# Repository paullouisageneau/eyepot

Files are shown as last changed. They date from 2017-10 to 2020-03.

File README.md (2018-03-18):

# Eyepot
A four-legged teapot robot with a camera

Read my blog articles for more information:

https://chapelierfou.org/blog/eyepot-a-creepy-teapot.html

https://chapelierfou.org/blog/eyepot-programming.html

https://vimeo.com/260540824

Eyepot

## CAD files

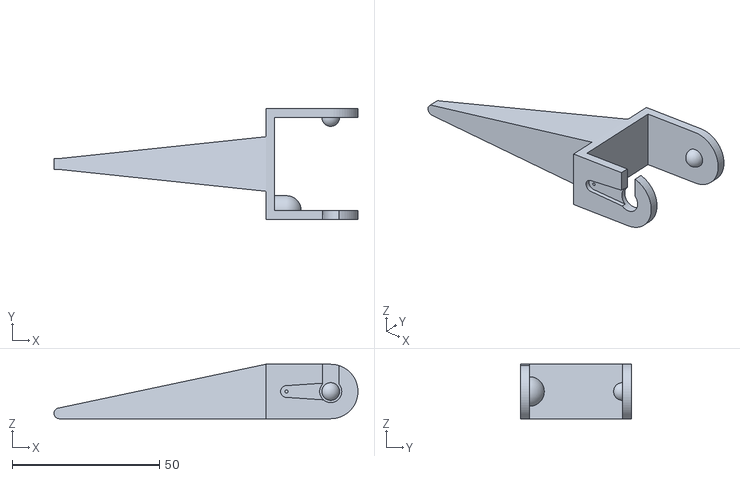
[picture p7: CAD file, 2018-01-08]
models/leg2.stl
103.1 x 37.5 x 18.5

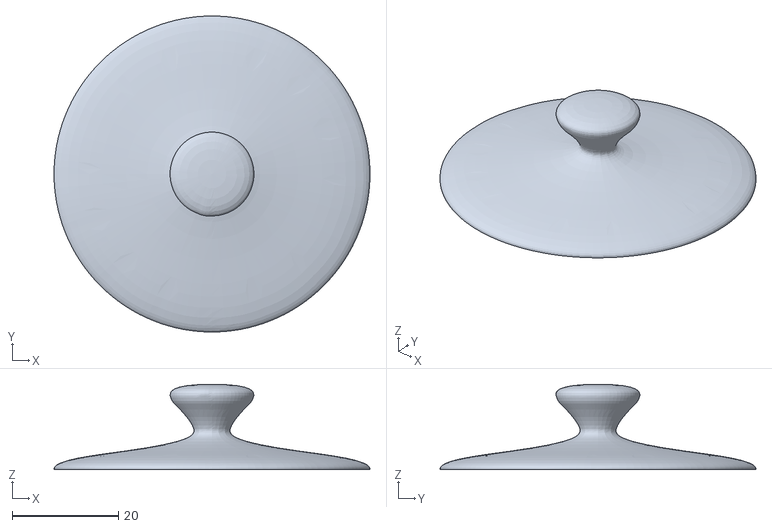
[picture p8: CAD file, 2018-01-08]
models/utah_lid.stl
59.4 x 59.4 x 16.0

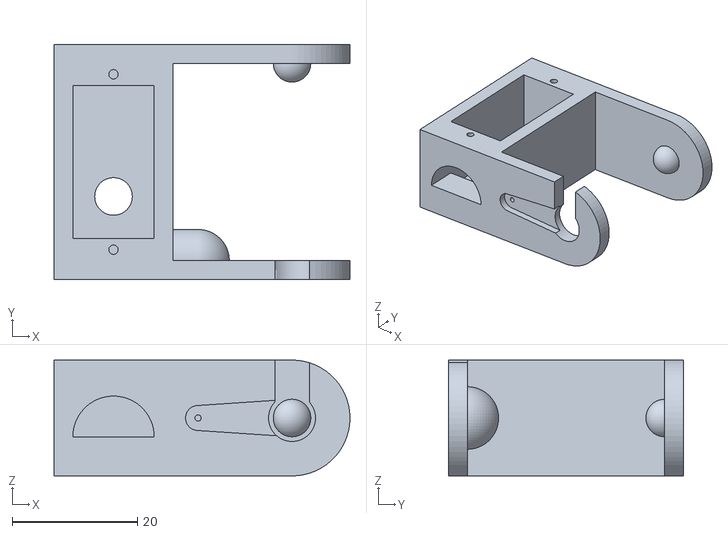
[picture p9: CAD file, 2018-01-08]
models/hip2.stl
47.2 x 37.5 x 18.5

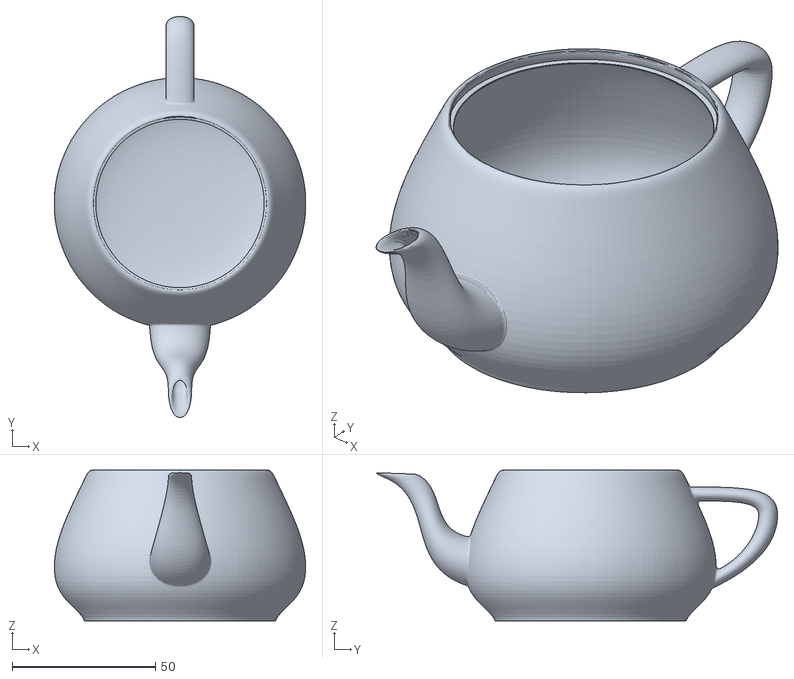
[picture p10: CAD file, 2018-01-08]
models/utah_teapot.stl
87.7 x 140.0 x 52.6

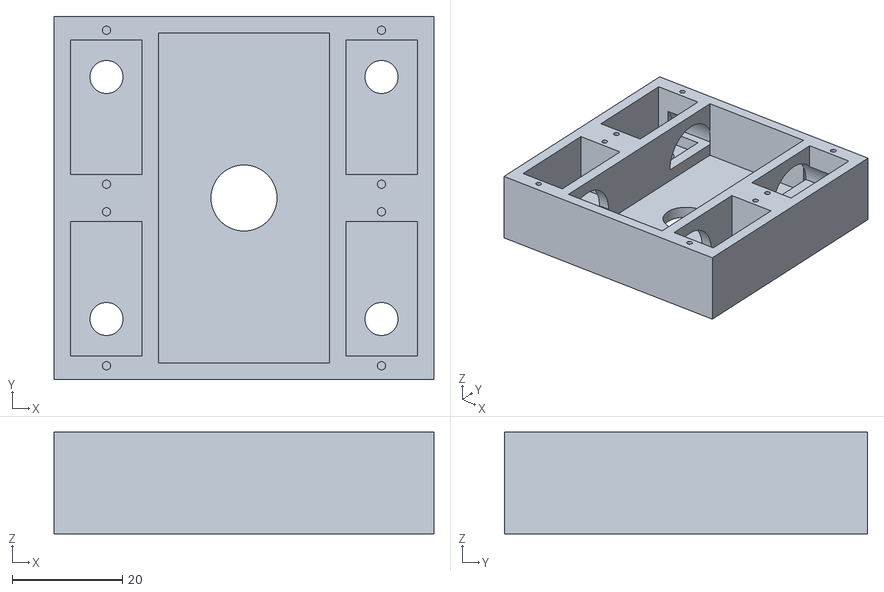
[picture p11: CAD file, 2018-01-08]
models/platform.stl
69.0 x 66.0 x 18.5

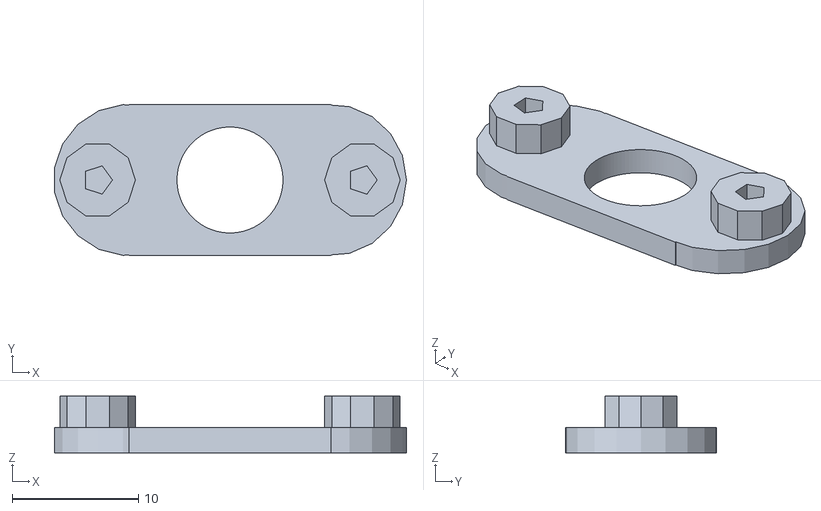
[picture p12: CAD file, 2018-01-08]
models/camera.stl
27.9 x 12.0 x 4.50

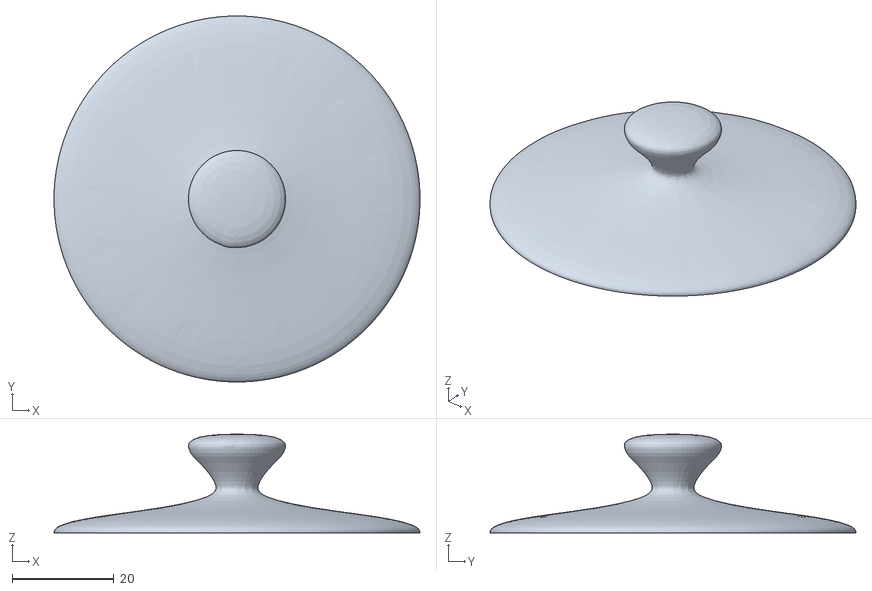
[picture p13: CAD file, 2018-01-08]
models/lid.stl
71.8 x 71.8 x 19.4

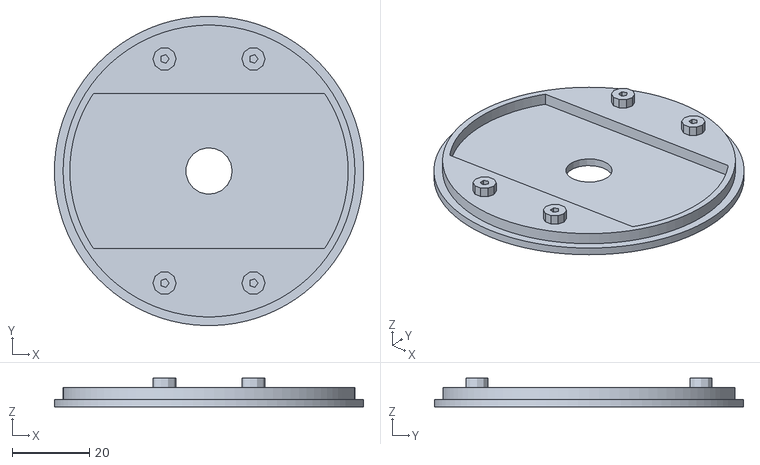
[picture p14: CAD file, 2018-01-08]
models/base.stl
80.0 x 80.0 x 7.50

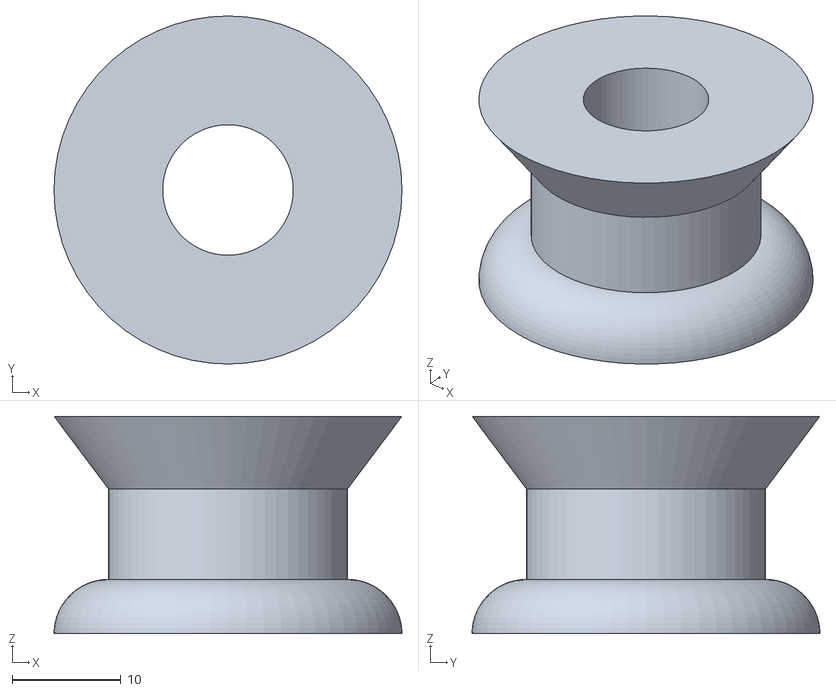
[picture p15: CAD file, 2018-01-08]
models/neck.stl
32.0 x 32.0 x 20.0

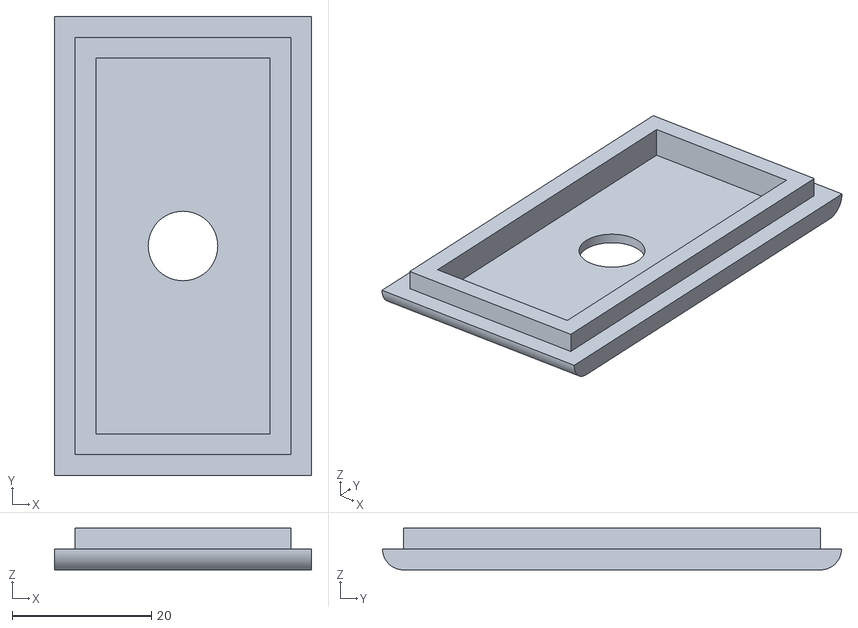
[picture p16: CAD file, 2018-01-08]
models/cover.stl
37.0 x 66.0 x 6.00

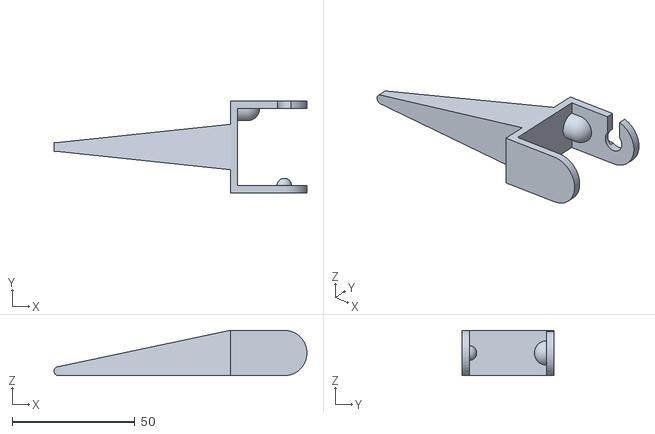
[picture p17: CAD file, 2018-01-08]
models/leg1.stl
103.1 x 37.5 x 18.5

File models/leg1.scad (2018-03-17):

/* 
 * Copyright (c) 2017 by Paul-Louis Ageneau
 *
 * This program is free software: you can redistribute it and/or modify
 * it under the terms of the GNU General Public License as published by
 * the Free Software Foundation, either version 3 of the License, or
 * (at your option) any later version.
 *
 * This program is distributed in the hope that it will be useful,
 * but WITHOUT ANY WARRANTY; without even the implied warranty of
 * MERCHANTABILITY or FITNESS FOR A PARTICULAR PURPOSE.  See the
 * GNU General Public License for more details.
 *
 * You should have received a copy of the GNU General Public License
 * along with this program.  If not, see <http://www.gnu.org/licenses/>.
 */

thickness = 3;
space = 22;

servo_width  = 23;
servo_depth  = 13;
servo_height = 22;
servo_height_total = 28.5;
servo_height_bottom = 15.5;
servo_axis_offset = 6;

height = servo_height_bottom + thickness;
length = 70;

$fn = 60;

union() {
    difference() {
        union() {
            cube([space, servo_height_total+thickness*3, height], center=true);
            translate([space/2, 0, 0]) rotate([90, 0, 0]) cylinder(h=servo_height_total+thickness*3, r=height/2, center=true);
        }
        union() {
            translate([50-space/2+thickness, 0, 0]) cube([100, servo_height_total+thickness, 100], center=true);
            translate([space/2, 50, 0]) rotate([90, 0, 0]) cylinder(h=100, r=3.75, center=true);
            translate([space/2, 50, 50]) cube([5.5, 100, 100], center=true);
            translate([space/2-15/2, servo_height_total/2+thickness, 0]) {
                rotate([0, -90, 0]) truncatedpyramid([6, 6], 15, 6/4*15, [0, 3, 0]);
                translate([-15/2, 0, 0]) rotate([-90, 0, 0]) cylinder(h=6, r=2);
                translate([-15/2, 0, 0]) rotate([-90, 0, 0]) cylinder(h=10, r=0.5, center=true);
            }
        }
    }

    translate([space/2, -(servo_height_total+thickness)/2, 0]) sphere(r=3, center=true);
    translate([space/2-15, (servo_height_total+thickness)/2+0.01, 0]) difference() {
        union() {
            sphere(r=5, center=true);
            translate([-5/2, 0, 0]) rotate([0, 90, 0]) cylinder(r=5, h=5, center=true);
        }
        translate([0, 50, 0]) cube([100, 100, 100], center=true);
    }

    translate([-space/2-length/2, 0, -height/2]) rotate([0, -90, 0]) { 
        truncatedpyramid([height, height], length, length*5, [height/2, 0, 0]);
        translate([(height/2)/5, 0, length/2]) scale([1, 1, 1]/5) rotate([90, 0, 0]) cylinder(h=height, r=height/2, center=true);
    }
}

module halfcylinder(h, r) {
    difference() {
        cylinder(h=h, r=r, center=true);
        translate([-r, 0, 0]) cube([r*2, r*4, h*2], center=true);
    }
}

module truncatedpyramid(p, z1, z2, t = [0, 0, 0]) {
    linear_extrude(height=z1, center=true, convexity=10, scale=z1/z2)
    translate(t) square(p, center = true);
}

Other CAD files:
models/hip1.stl
models/leg2.scad
models/base.scad
models/camera.scad
models/cover.scad
models/hip1.scad
models/hip2.scad
models/lid.scad
models/neck.scad
models/platform.scad
models/top.scad

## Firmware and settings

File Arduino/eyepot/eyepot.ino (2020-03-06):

/*
 * Copyright (C) 2017 by Paul-Louis Ageneau
 * paul-louis (at) ageneau (dot) org
 *
 * This file is part of Eyepot.
 *
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
 * You should have received a copy of the GNU General Public License
 * along with this program. If not, see <http://www.gnu.org/licenses/>.
 */

#include <Servo.h>

// ---------- Pin setup ----------
const int servoPins[8] = {5, 6, 7, 8, 9, 10, 11, 12};
const int offsetAngles[8] = { -5, 0, -10, -5, -10, 5, 10, -5 };
const int defaultAngles[8] = { 135, 135, 45, 45, 90, 90, 90, 90 };

const int batteryProbePin = A0;
const long batteryProbeFactor = 10200L;
const int batteryVoltageMin = 6300;
const int batteryVoltageMax = 8300;

int batteryProbeCount = 0;

Servo servos[8];
unsigned int angles[8];

String inputString = "";

void setup()
{
  // Init serial
  Serial.begin(9600);

  // Init servos
  for(int i = 0; i < 8; ++i)
  {
    angles[i] = defaultAngles[i];
    servos[i].attach(servoPins[i]);
    servos[i].write(offsetAngles[i] + angles[i]);
  }

  // Activity LED
  pinMode(13, OUTPUT);
  digitalWrite(LED_BUILTIN, HIGH);
  delay(100);
  digitalWrite(LED_BUILTIN, LOW);
}

void loop()
{
  int batteryVoltage = int(long(analogRead(batteryProbePin))*batteryProbeFactor/1024L);  // mV
  int batteryPercent = constrain(map(batteryVoltage, batteryVoltageMin, batteryVoltageMax, 0, 100), 0, 100);

  // Exit on low battery
  if(batteryPercent == 0)
  {
    ++batteryProbeCount;
    if(batteryProbeCount == 100)
    {
      Serial.println("B 0");
      for(int i = 0; i < 8; ++i)
      {
          servos[i].detach();
      }
      exit(0);
    }
    batteryPercent = 1;
  }
  else {
    batteryProbeCount = 0;
  }

  // Read commands on serial
  while(Serial.available())
  {
    char chr = (char)Serial.read();
    if(chr != '\n')
    {
      if(chr != '\r')
        inputString+= chr;
    }
    else if(inputString.length() > 0)
    {
      // Parse command
      char cmd = toupper(inputString[0]);
      String param;
      int pos = 1;
      while(pos < inputString.length() && inputString[pos] == ' ') ++pos;
      param = inputString.substring(pos);

      // Execute command
      if(cmd >= '0' && cmd < '8') // Servo
      {
        int i = int(cmd) - int('0');
        int angle = param.toInt();
        angles[i] = angle;
      }
      else if(cmd == 'R')        // Reset
      {
        for(int i = 0; i < 8; ++i)
          angles[i] = defaultAngles[i];
      }
      else if(cmd == 'C')        // Commit
      {
        for(int i = 0; i < 8; ++i)
          servos[i].write(offsetAngles[i] + angles[i]);
      }
      else if(cmd == 'B')        // Battery
      {
        Serial.print("B ");
        Serial.print(batteryPercent);
        Serial.println();
      }

      inputString = "";
    }
  }
}

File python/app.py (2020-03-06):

'''
    Copyright (C) 2017 by Paul-Louis Ageneau
    paul-louis (at) ageneau (dot) org

    This file is part of Eyepot.

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
    You should have received a copy of the GNU Affero General Public
    License along with Eyepot.
    If not, see <http://www.gnu.org/licenses/>.
'''

import control
import controlthread

from flask import Flask, request, Response, send_file, url_for, jsonify

app = Flask(__name__)
app.config.from_object(__name__)

ctrl = control.Control('/dev/serial0', 9600)
ctrl.start()
ctrlThread = controlthread.ControlThread(ctrl)
ctrlThread.start()

@app.route('/', methods=['GET'])
def home():
    return send_file('static/index.html')

@app.route('/move', methods=['POST'])
def move():
	data = request.get_json()
	ctrlThread.state = data["state"] if data["state"] else 'idle'
	return Response('', 200)

@app.route('/battery', methods=['GET'])
def battery():
    return jsonify({"level": ctrl.battery_level})


if __name__ == '__main__':
	app.run(host = '0.0.0.0', port = 8080)

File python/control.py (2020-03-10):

'''
    Copyright (C) 2017 by Paul-Louis Ageneau
    paul-louis (at) ageneau (dot) org

    This file is part of Eyepot.

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
    You should have received a copy of the GNU Affero General Public
    License along with Eyepot.
    If not, see <http://www.gnu.org/licenses/>.
'''

import serial
import time
import threading

class Control(threading.Thread):

    def __init__(self, device = '/dev/serial0', baudrate = 9600):
        super().__init__()
        self.ser = serial.Serial(device, baudrate, timeout = 1)
        self.battery_level = 100

    def run(self):
        while self.ser.is_open:
            self.send('B')
            while True:
                command = self.read()
                if not command:
                    break
                self.process(command)

    def reset(self):
        self.send('R')

    def commit(self):
        self.send('C')

    def send(self, command):
        self.ser.write((command + '\n').encode())

    def read(self):
        return self.ser.readline().decode()

    def process(self, command):
        c = command[0]
        arg = command[1:].strip()
        if c == 'B':
            self.battery_level = int(arg)

    # leg angle > 0 => down
    def leg(self, i, angle):
        self.move(i, 90+angle if i < 2 else 90-angle)

    # hip angle > 0 => front
    def hip(self, i, angle):
        self.move(4+i, 90+angle if i < 2 else 90-angle)

    def move(self, servo, angle):
        if servo >= 0 and servo < 8:
            angle = min(max(angle, 0), 180)
            self.send('{:s}{:d}'.format(chr(ord('0')+servo), int(angle)))

    def idle(self):
        self.reset()
        self.commit()
        time.sleep(0.1)

    def translateFront(self, f = 25):
        self.walk(f, 0, 0)

    def translateBack(self, f = 25):
        self.walk(-f, 0, 0)

    def translateRight(self, f = 25):
        self.walk(0, f, 0)

    def translateLeft(self, f = 25):
        self.walk(0, -f, 0)

    def rotateRight(self, f = 25):
        #self._pattern1(20, 0, [30, 30, -30, -30], [0, 3, 1, 2], 0.2)
        self.walk(0, 0, f)

    def rotateLeft(self, f = 25):
        #self._pattern1(20, 0, [-30, -30, 30, 30], [2, 1, 3, 0], 0.2)
        self.walk(0, 0, -f)

    def walk(self, forward, sideward, rotation):
        fu = [1, 1, 1, 1]
        su = [-1, 1, 1, -1]
        ru = [1, 1, -1, -1]
        v = [f*forward + s*sideward + r*rotation for f, s, r in zip(fu, su, ru)]
        self._pattern2(30, 5, v, 0.15)

    def _pattern1(self, ldown, lup, hangles, legs, step):
        for i in legs:
            self.leg(i, ldown)
            self.hip(i, lup)
        self.commit()
        time.sleep(step)

        for i in legs:
            self.leg(i, lup)
            self.hip(i, hangles[i])
            self.commit()
            time.sleep(step/2)

            self.leg(i, ldown)
            self.commit()
            time.sleep(step/2)

    def _pattern2(self, ldown, lup, hangles, step):
        offsets = [-a/4 for a in hangles]

        self.leg(0, lup)
        self.leg(1, ldown)
        self.leg(2, ldown)
        self.leg(3, lup)
        self.commit()
        time.sleep(step/2)

        self.hip(0, offsets[0] + hangles[0])
        self.hip(1, offsets[1])
        self.hip(2, offsets[2])
        self.hip(3, offsets[3] + hangles[3])
        self.commit()
        time.sleep(step/2)

        self.leg(0, ldown)
        self.leg(3, ldown)
        self.commit()
        time.sleep(step/2)

        self.hip(0, offsets[0])
        self.hip(1, offsets[1] - hangles[1])
        self.hip(2, offsets[2] - hangles[2])
        self.hip(3, offsets[3])
        self.commit()
        time.sleep(step/2)

        self.leg(0, ldown)
        self.leg(1, lup)
        self.leg(2, lup)
        self.leg(3, ldown)
        self.commit()
        time.sleep(step/2)

        self.hip(0, offsets[0])
        self.hip(1, offsets[1] + hangles[1])
        self.hip(2, offsets[2] + hangles[2])
        self.hip(3, offsets[3])
        self.commit()
        time.sleep(step/2)

        self.leg(1, ldown)
        self.leg(2, ldown)
        self.commit()
        time.sleep(step/2)

        self.hip(0, offsets[0] - hangles[0])
        self.hip(1, offsets[1])
        self.hip(2, offsets[2])
        self.hip(3, offsets[3] - hangles[3])
        self.commit()
        time.sleep(step/2)

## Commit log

2017-11-15 Added comments to Arduino code
2018-01-08 Added models
    [base.scad, base.stl, camera.scad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]
2018-03-13 Added configuration
    [janus.plugin.streaming.cfg]
2018-03-17 Added license to models
    [base.scad, camera.scad, cover.scad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]
2020-03-06 Added battery level probing

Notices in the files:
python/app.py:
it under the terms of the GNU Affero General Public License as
